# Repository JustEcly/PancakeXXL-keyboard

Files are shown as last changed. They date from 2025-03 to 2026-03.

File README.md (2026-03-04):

# PancakeXXL keyboard

  

This 40% is made in the idea of a little keyboard easy to travel with is little format and is 3d printed case to be lightweight.
This keyboard is made QMK and work with VIAL to make it customisable by everyone ! 

## Special thanks
I made it integrally but I take for inspiration for the layout the [Tanuki](https://github.com/SethSenpai/Tanuki) and get help from the [HLB team](https://github.com/H3lli0n/HLB-Projects) for some aspect of the keyboard (especially thanks to Please to help me with the PCB part and Hellion to help me with the case and firmware problems)

---
# Layout
Like say earlier I took inspiration of the Tanuki for the layout, but modify the last row by making it with a center Fn and not on the side, I also make it compatible with a 7u option.
To use the 7u layout you gonna need a special plate in the [plate and case directory](/plate_and_case/) who's using clip-in 7u stab (using 7u screw-in stab would have caused overlapping issues with switches) and activate the option on vial in the Layout tab
 ## Layout 2x2u and 7u
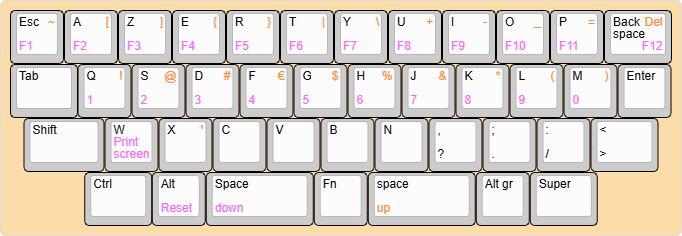
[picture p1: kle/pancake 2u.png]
Layout 2x2u

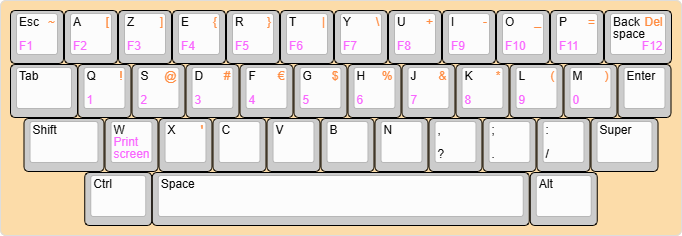
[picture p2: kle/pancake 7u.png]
Layout 7u


With the 2x2u you have an hold mod to use the up and down layer, you can customise it if you prefer to don't have it.

---
# QMK
The keyboard is made with a RP2040 MCU from rasbperry pi integrated on the PCB itself. This is a powerful MCU capable of a lot of thing like using QMK and by extension the VIAL application for easy modification of the keyboard.

---
# How to install the firmware
To install the firmware, you just need the uf2 files you can find in the [realease](https://github.com/JustEcly/PancakeXXL-keyboard/releases) or in the firmawre folder in the "[production_files](/production_files/firmware/)"
After downloading it, you need to connect the keyboard to your computer and slide the uf2 files in the directory that just open

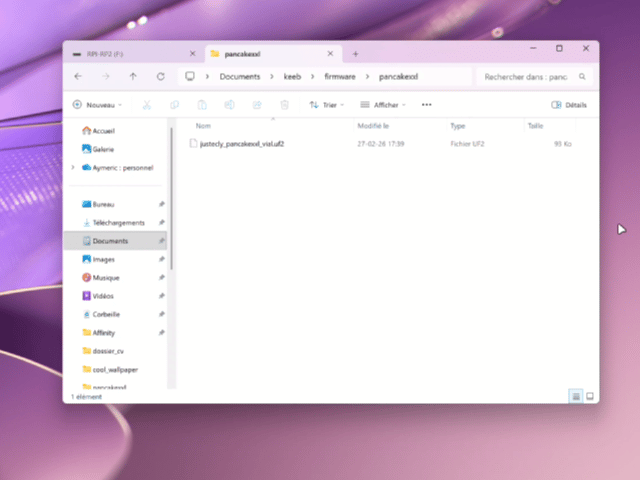
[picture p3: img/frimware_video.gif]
firmawre_video


Good job ! You now have a functionnal PCB & keyboard 👍

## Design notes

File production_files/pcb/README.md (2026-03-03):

# WARNING
some of the composant are'nt in the right position, to be sure to make a working pcb be sure to have the right orientation like the image below :
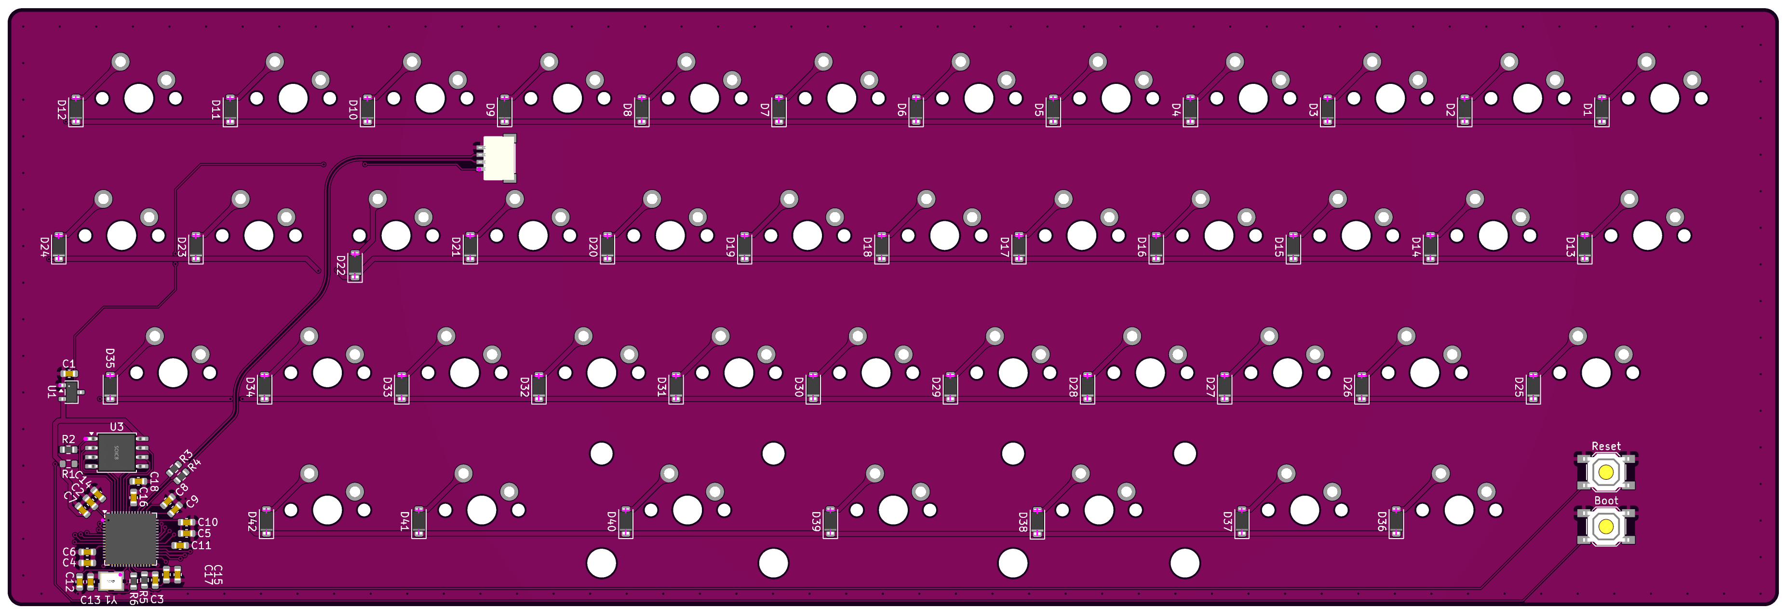
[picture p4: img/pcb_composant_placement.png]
image of the composant placement


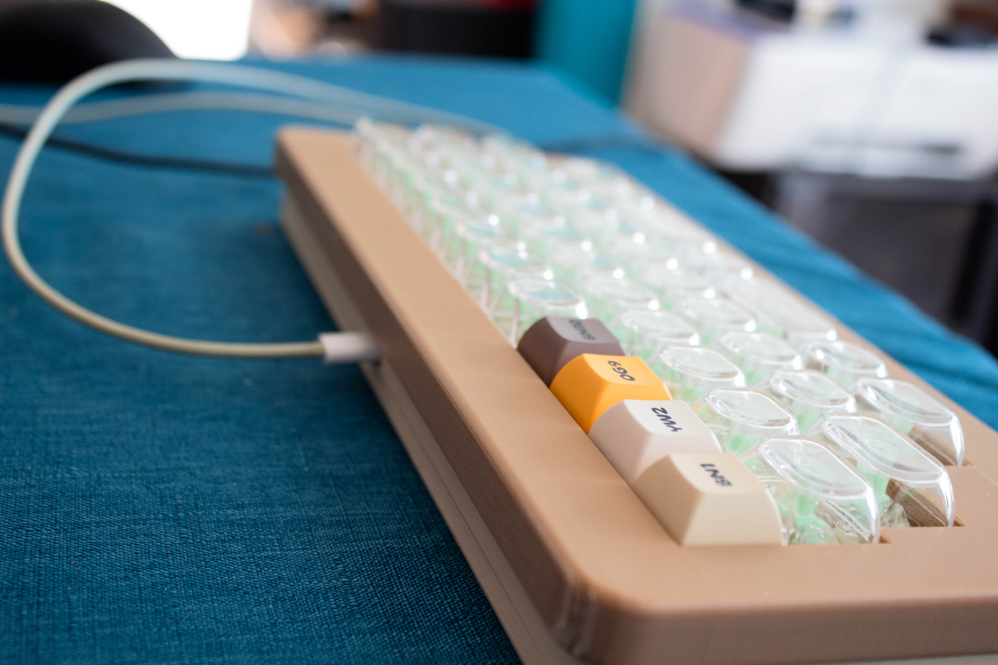
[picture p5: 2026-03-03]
img/pancakexxl_proto4-5.jpg

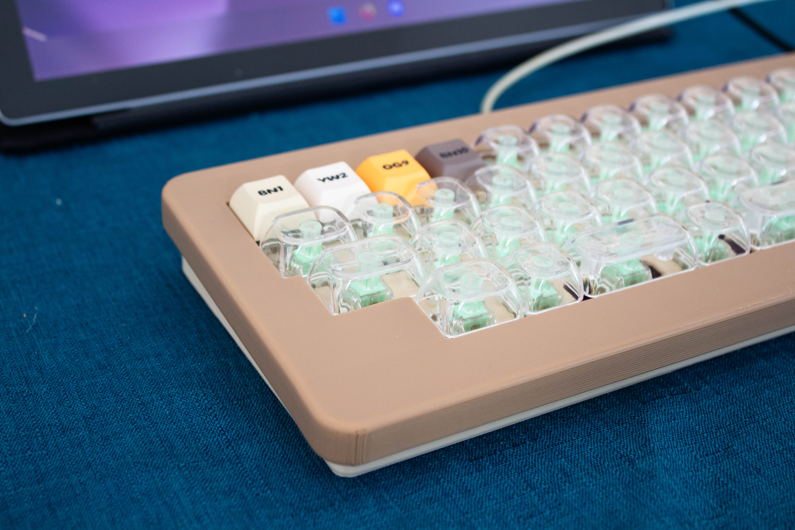
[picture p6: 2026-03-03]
img/pancakexxl_proto4-2.jpg

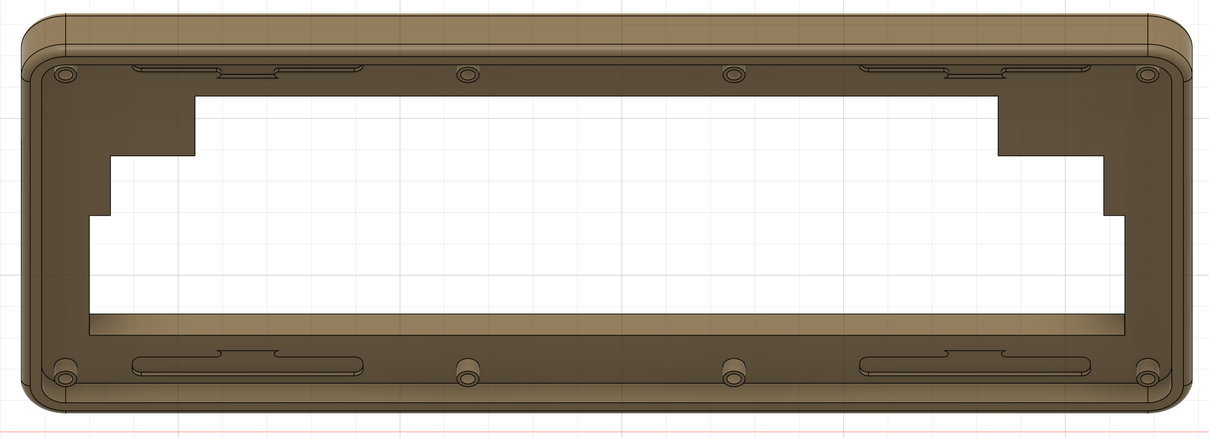
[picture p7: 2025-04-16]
plate_and_case/img/Back top-case.png

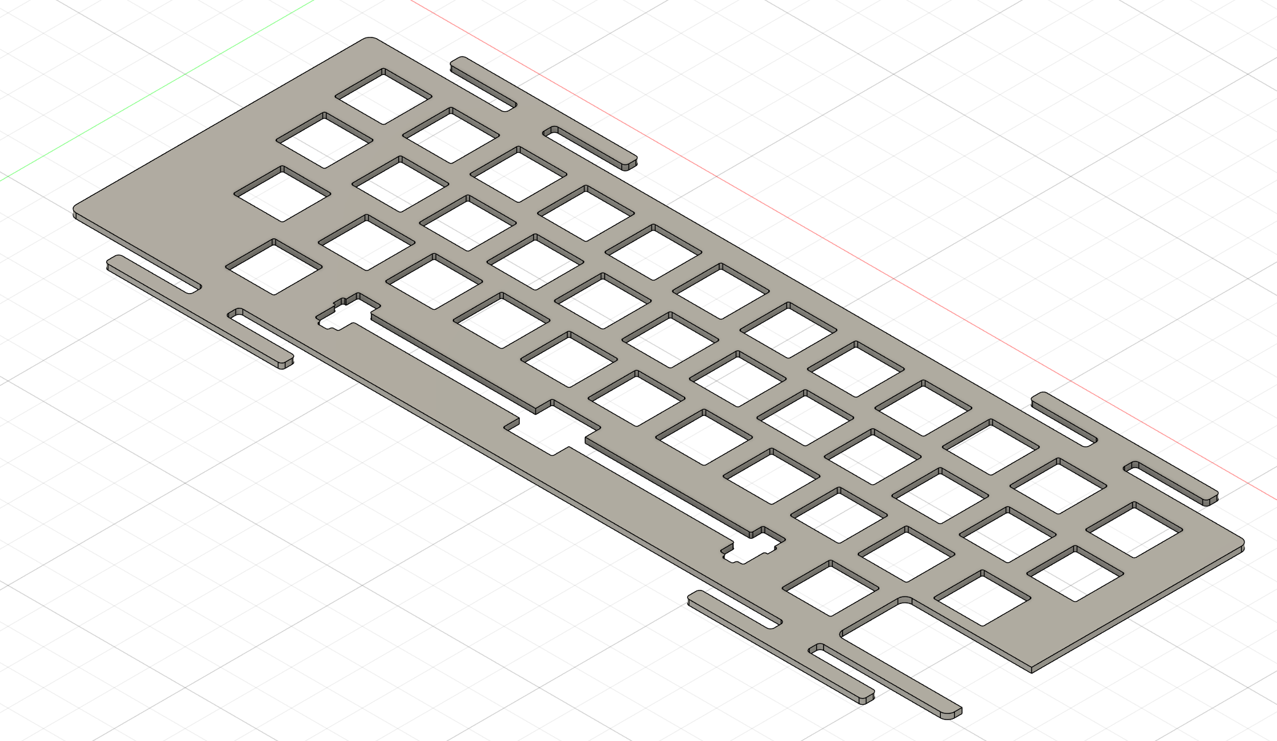
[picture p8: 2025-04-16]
plate_and_case/img/Plate 7u.png

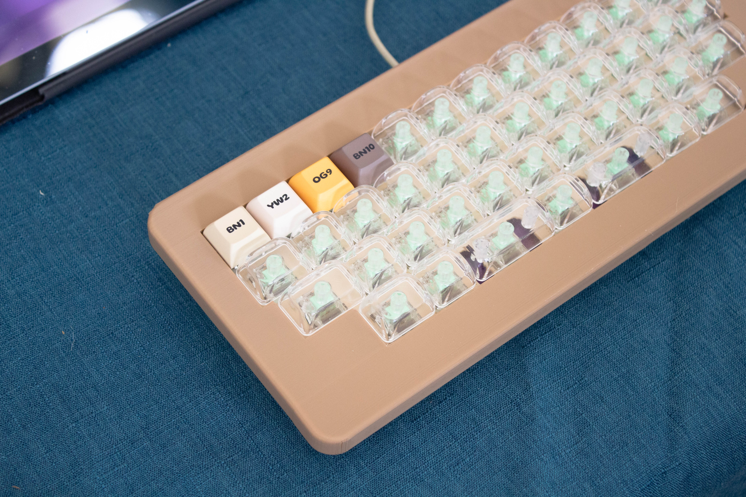
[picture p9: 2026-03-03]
img/pancakexxl_proto4-1.jpg

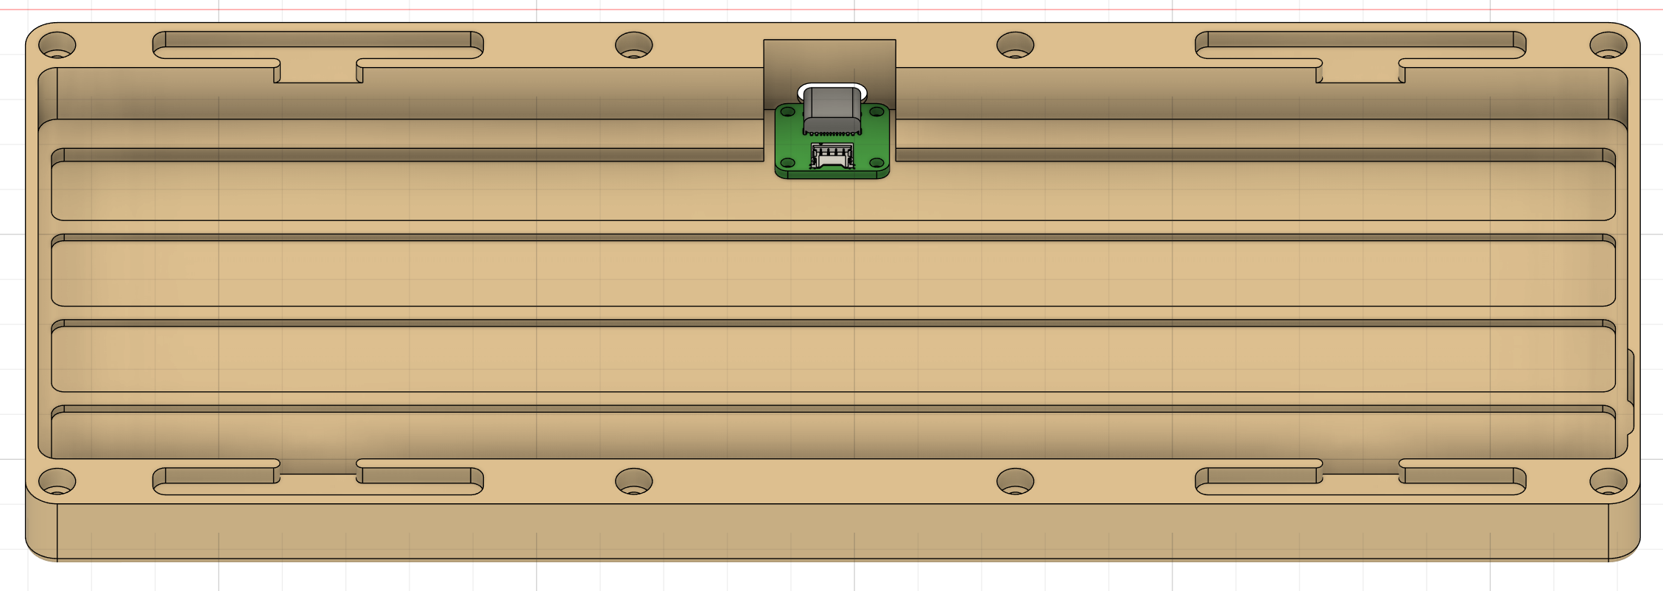
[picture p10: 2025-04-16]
plate_and_case/img/front bottom-case + UDB.png

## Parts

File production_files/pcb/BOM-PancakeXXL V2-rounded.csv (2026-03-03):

Comment | Designator | Footprint | LCSC | Quantity
100n | C11,C14,C15,C16,C17,C3,C4,C5,C6,C7,C8,C9 | C_0603_1608Metric | C1590 | 12
10u | C2 | C_0603_1608Metric | C1691 | 1
10uF | C1 | C_0603_1608Metric | C1691 | 1
15p | C12,C13 | C_0603_1608Metric | C1644 | 2
1K | R2 | R_0603_1608Metric | C103209 | 1
1k | R5,R6 | R_0603_1608Metric | C103209 | 2
1u | C10,C18 | C_0603_1608Metric | C1592 | 2
27.4 | R3,R4 | R_0603_1608Metric | C22926 | 2
ABM8-272-T3 | Y1 | ABM8-272-T3_ABR | C20625731 | 1
Boot | Boot | SW_SPST_SKQG_WithStem | C115351 | 1
Conn_01x04 | J1 | JST-SR-4 | C160404 | 1
D_Small | D1,D10,D11,D12,D13,D14,D15,D16,D17,D18,D19,D2,D20,D21,D22,D23,D24,D25,D26,D27,D28,D29,D3,D30,D31,D32,D33,D34,D35,D36,D37,D38,D39,D4,D40,D41,D42,D5,D6,D7,D8,D9 | D_SOD-123 | C7370889 | 42
RP2040 | U2 | QFN-56-1EP_7x7mm_P0.4mm_EP3.2x3.2mm | C2040 | 1
Reset | Reset | SW_SPST_SKQG_WithStem | C115351 | 1
W25Q128JVS | U3 | SOIC-8_5.23x5.23mm_P1.27mm | C97521 | 1
XC6206PxxxMR | U1 | SOT-23-3 | C5446 | 1
MX-NoLED | MX16 | MX_PCB_1.00u |  | 1
MX-NoLED | MX32 | MX_PCB_1.00u |  | 1
MX-NoLED | MX12 | MX_PCB_1.25u |  | 1
MX-NoLED | MX6 | MX_PCB_1.00u |  | 1
MX-NoLED | MX27 | MX_PCB_1.00u |  | 1
MX-NoLED | MX35 | MX_PCB_1.25u |  | 1
MX-NoLED | MX38 | MX_PCB_2.00u |  | 1
MX-NoLED | MX28 | MX_PCB_1.00u |  | 1
MX-NoLED | MX40 | MX_PCB_2.00u |  | 1
MX-NoLED | MX1 | MX_PCB_1.00u |  | 1
MX-NoLED | MX31 | MX_PCB_1.00u |  | 1
MX-NoLED | MX36 | MX_PCB_1.25u |  | 1
MX-NoLED | MX42 | MX_PCB_1.25u |  | 1
MX-NoLED | MX26 | MX_PCB_1.00u |  | 1
MX-NoLED | MX34 | MX_PCB_1.00u |  | 1
MX-NoLED | MX37 | MX_PCB_1.00u |  | 1
MX-NoLED | MX10 | MX_PCB_1.00u |  | 1
MX-NoLED | MX20 | MX_PCB_1.00u |  | 1
MX-NoLED | MX30 | MX_PCB_1.00u |  | 1
MX-NoLED | MX23 | MX_PCB_1.00u |  | 1
MX-NoLED | MX13 | MX_PCB_1.25u |  | 1
MX-NoLED | MX2 | MX_PCB_1.00u |  | 1
MX-NoLED | MX18 | MX_PCB_1.00u |  | 1
MX-NoLED | MX24 | MX_PCB_1.00u |  | 1
MX-NoLED | MX7 | MX_PCB_1.00u |  | 1
MX-NoLED | MX5 | MX_PCB_1.00u |  | 1
MX-NoLED | MX33 | MX_PCB_1.00u |  | 1
MX-NoLED | MX4 | MX_PCB_1.00u |  | 1
MX-NoLED | MX11 | MX_PCB_1.00u |  | 1
MX-NoLED | MX9 | MX_PCB_1.00u |  | 1
MX-NoLED | MX19 | MX_PCB_1.00u |  | 1
MX-NoLED | MX14 | MX_PCB_1.00u |  | 1
MX-NoLED | MX39 | MX_PCB_1.00u |  | 1
MX-NoLED | MX17 | MX_PCB_1.00u |  | 1
MX-NoLED | MX22 | MX_PCB_1.00u |  | 1
MX-NoLED | MX41 | MX_PCB_1.00u |  | 1
MX-NoLED | MX21 | MX_PCB_1.00u |  | 1
MX-NoLED | MX8 | MX_PCB_1.00u |  | 1
MX-NoLED | MX29 | MX_PCB_1.00u |  | 1
MX-NoLED | MX3 | MX_PCB_1.00u |  | 1
MX-NoLED | MX15 | MX_PCB_1.00u |  | 1
MX-NoLED | MX25 | MX_PCB_1.50u |  | 1
DNF | R1 | R_0603_1608Metric |  | 1

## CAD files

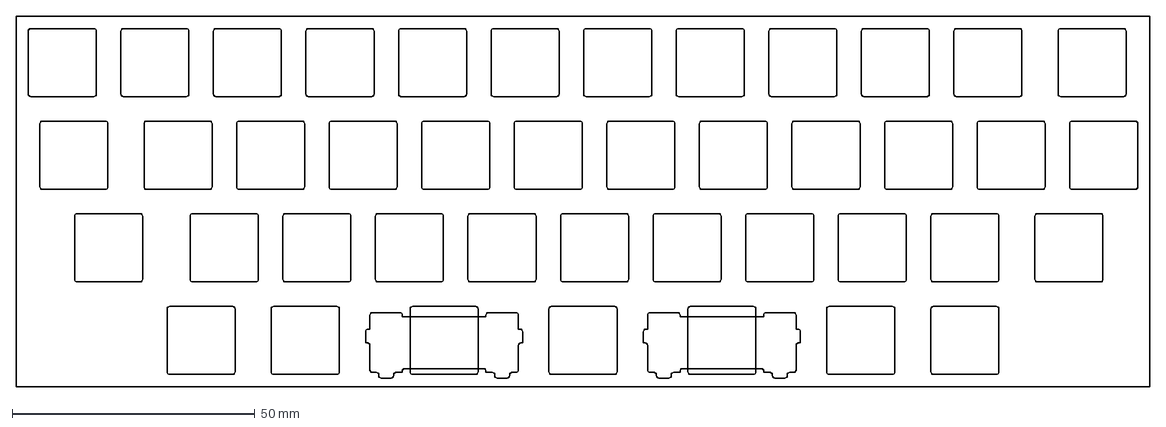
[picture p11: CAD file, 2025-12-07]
plate_and_case/dxf (PCB & Plate)/2U clip.dxf
233.4 x 76.2 mm

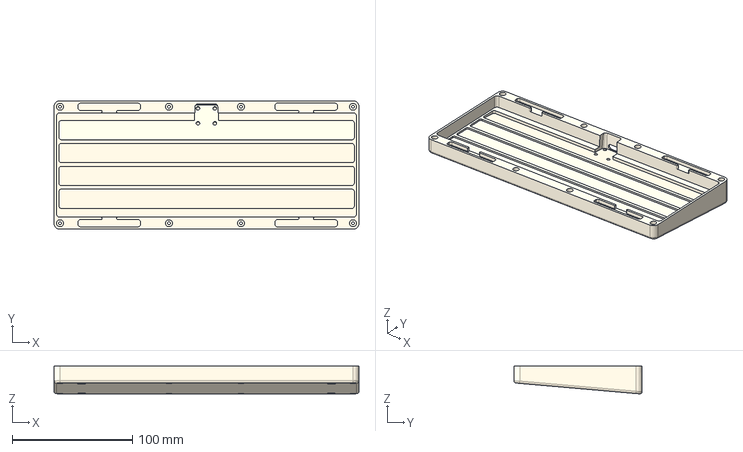
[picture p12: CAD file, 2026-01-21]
production_files/plate_and_case/step/Bottom case (v0.5).step
254.0 x 107.0 x 23.2 mm

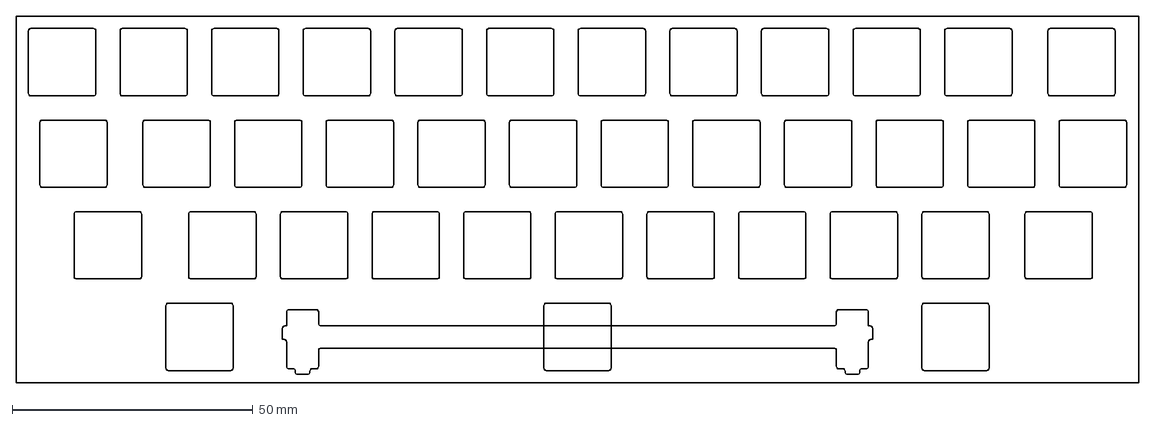
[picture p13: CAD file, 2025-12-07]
plate_and_case/dxf (PCB & Plate)/7u clip.dxf
233.4 x 76.2 mm

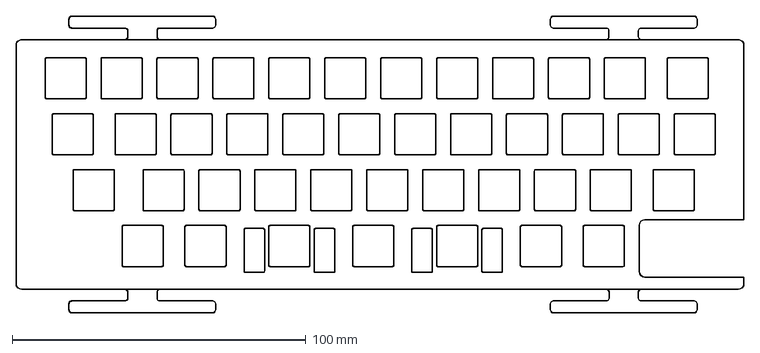
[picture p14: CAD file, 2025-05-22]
plate_and_case/Foam/Foam 2u.dxf
248.0 x 101.0 mm

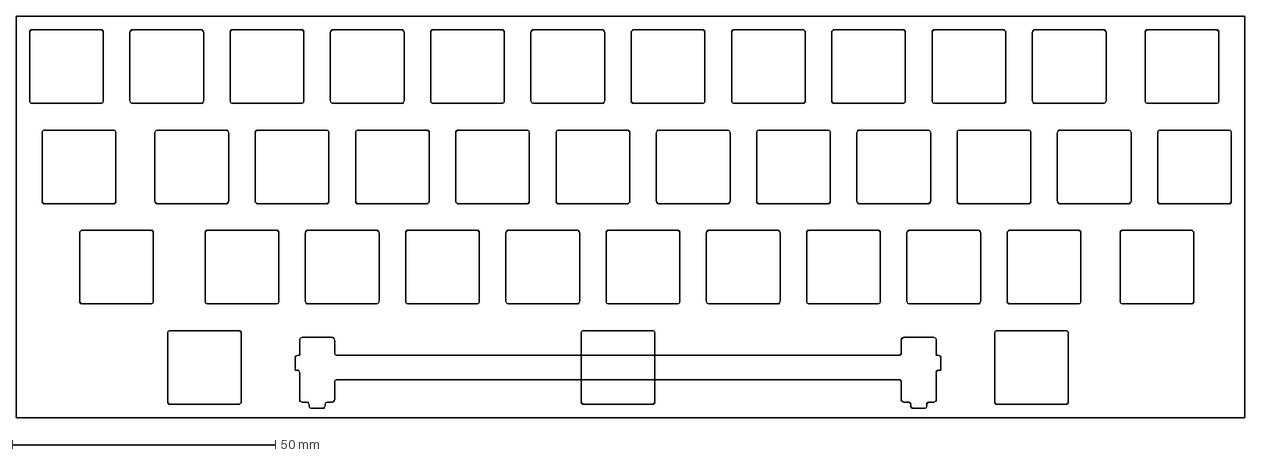
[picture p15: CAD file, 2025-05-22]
plate_and_case/Plate Ai03 - dxf & svg/7u clip.dxf
233.4 x 76.2 mm

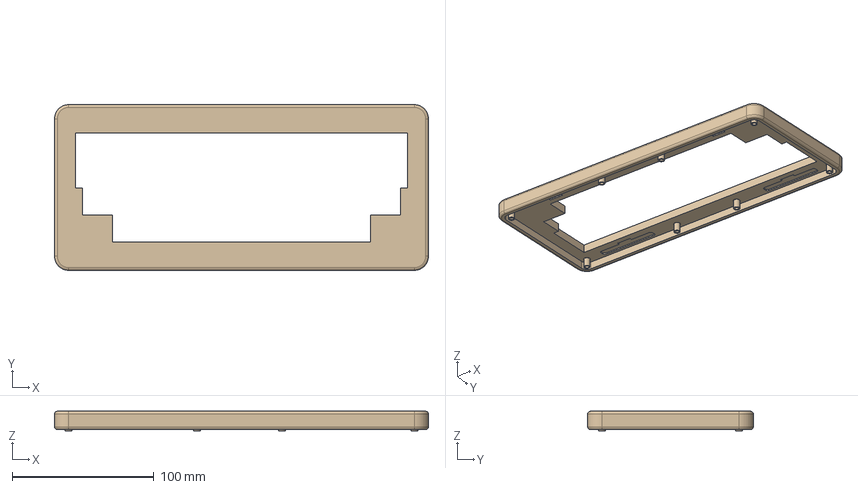
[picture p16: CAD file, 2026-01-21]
production_files/plate_and_case/step/Top case (v0.5).step
264.0 x 117.0 x 13.8 mm

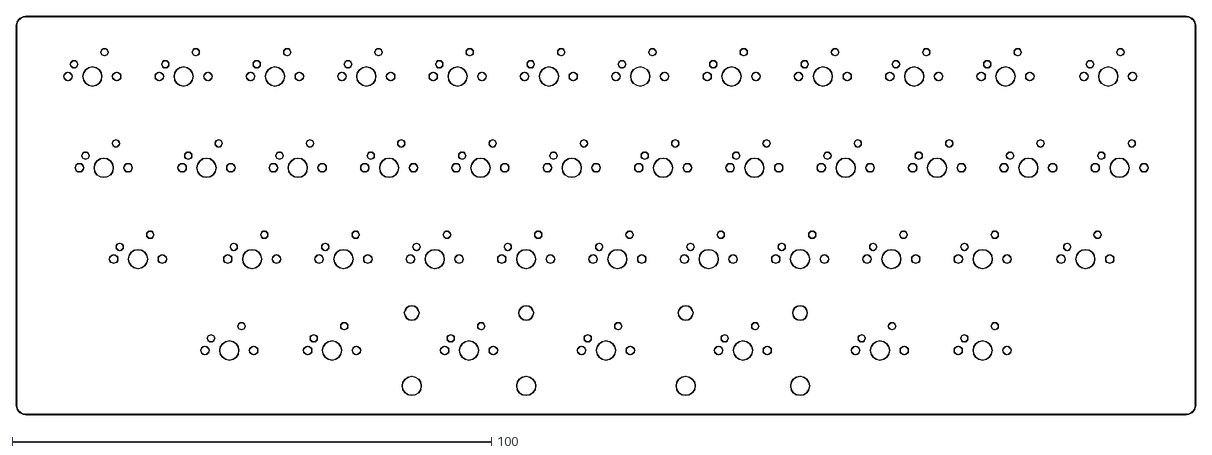
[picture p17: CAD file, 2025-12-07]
plate_and_case/dxf (PCB & Plate)/PancakeXXL V2-rounded-Edge_Cuts.dxf
246.1 x 83.0

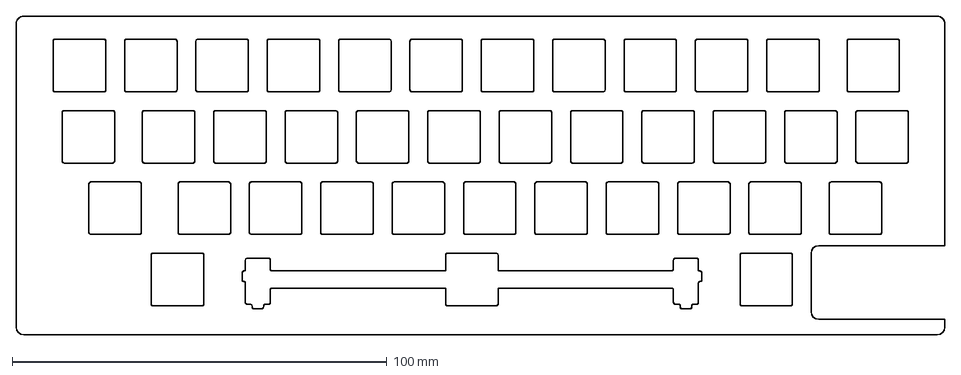
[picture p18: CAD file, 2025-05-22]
plate_and_case/Foam/Plate 7u clip.dxf
248.0 x 85.0 mm

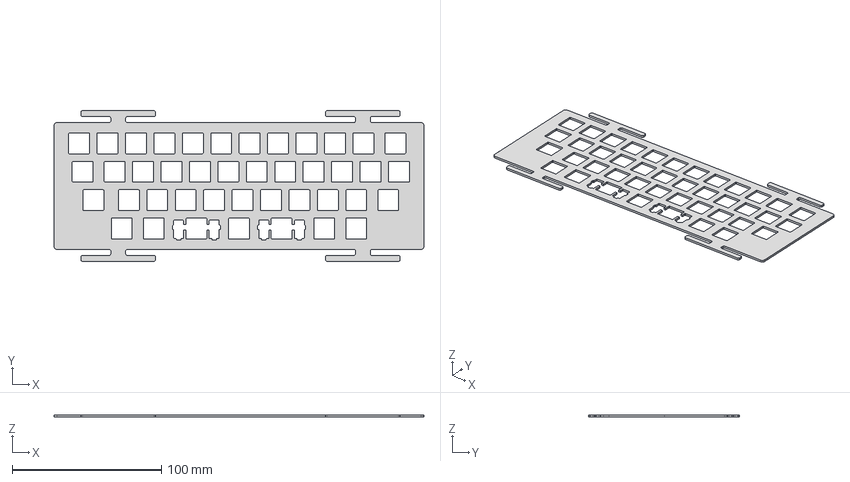
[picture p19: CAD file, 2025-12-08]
production_files/plate_and_case/step/Plate 2u Clip (v0.4).step
248.0 x 101.0 x 1.50 mm

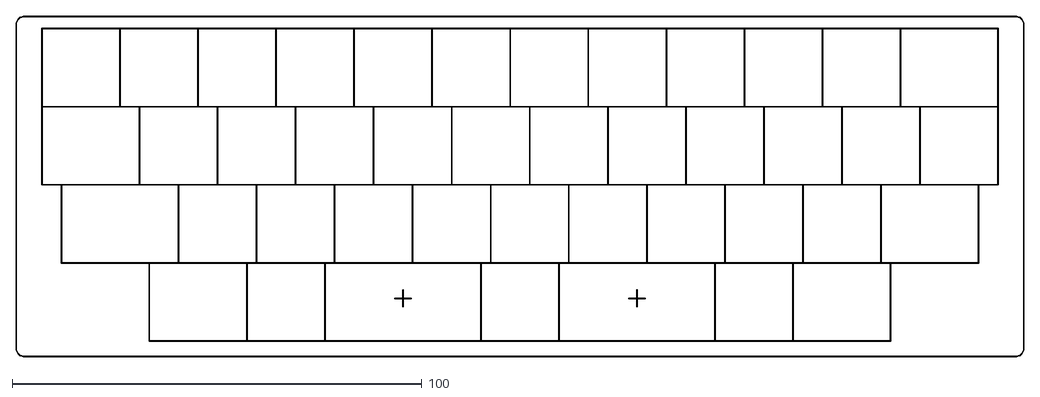
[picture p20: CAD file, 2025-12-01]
plate_and_case/dxf (PCB & Plate)/Trou top case.dxf
246.1 x 83.0

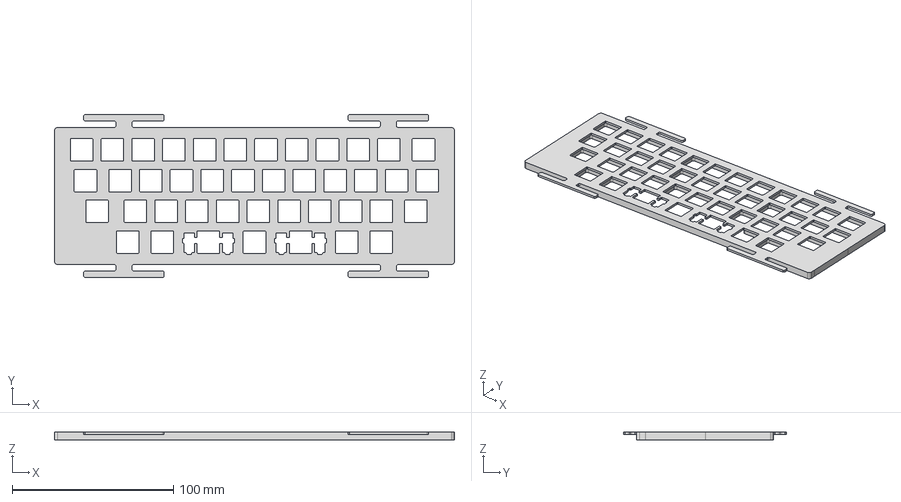
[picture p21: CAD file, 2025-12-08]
production_files/plate_and_case/step/Plate 2u Clip (3dp renfort) (v0.4).step
248.0 x 101.0 x 4.90 mm

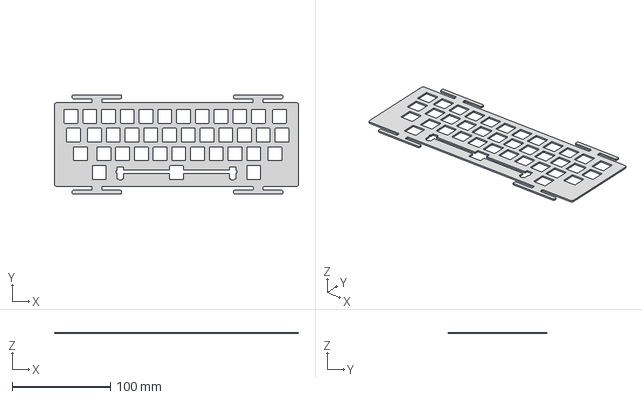
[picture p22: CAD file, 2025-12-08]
production_files/plate_and_case/step/Plate 7u clip (v0.4).step
248.0 x 101.0 x 1.50 mm

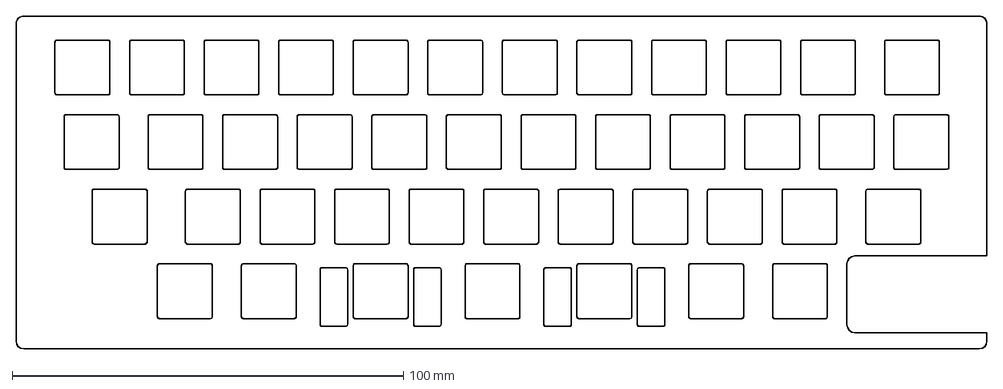
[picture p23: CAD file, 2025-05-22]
plate_and_case/Foam/Plate 2u Screw.dxf
248.0 x 85.0 mm

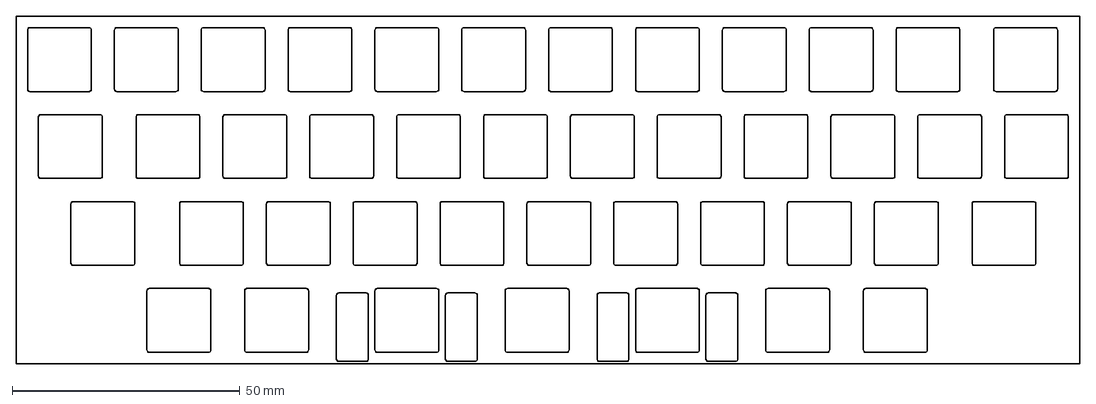
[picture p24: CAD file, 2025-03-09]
plate_and_case/Plate Ai03 - dxf & svg/2u screw.dxf
233.4 x 76.2 mm

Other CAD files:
production_files/plate_and_case/step/Plate 2u screw (v0.4).step
production_files/plate_and_case/stl/Bottom case (v0.5).stl
production_files/plate_and_case/stl/Plate 2u Clip (3dp renfort) (v0.4).stl
production_files/plate_and_case/stl/Plate 2u Clip (v0.4).stl
production_files/plate_and_case/stl/Plate 2u screw (v0.4).stl
production_files/plate_and_case/stl/Plate 7u clip (v0.4).stl
production_files/plate_and_case/stl/Top case (v0.5).stl

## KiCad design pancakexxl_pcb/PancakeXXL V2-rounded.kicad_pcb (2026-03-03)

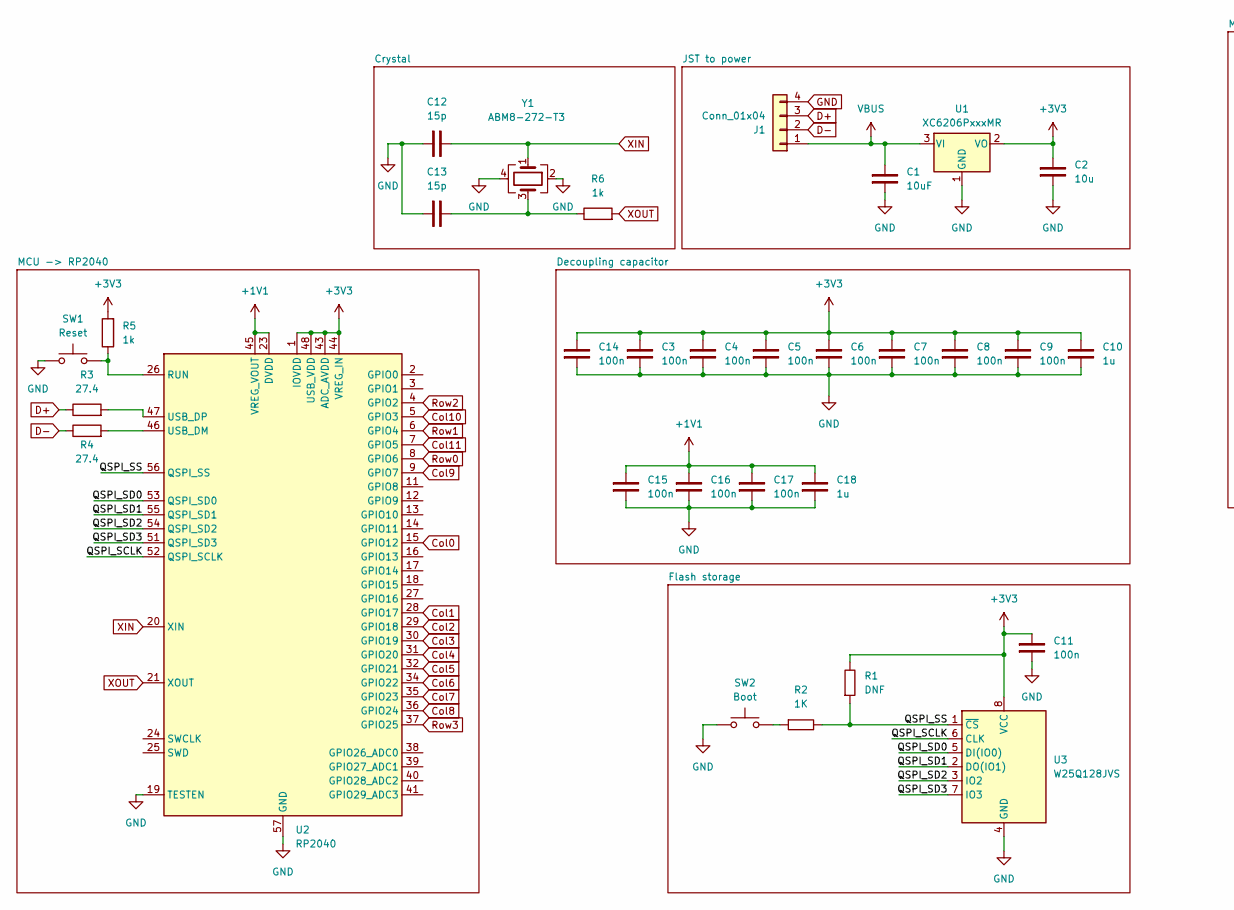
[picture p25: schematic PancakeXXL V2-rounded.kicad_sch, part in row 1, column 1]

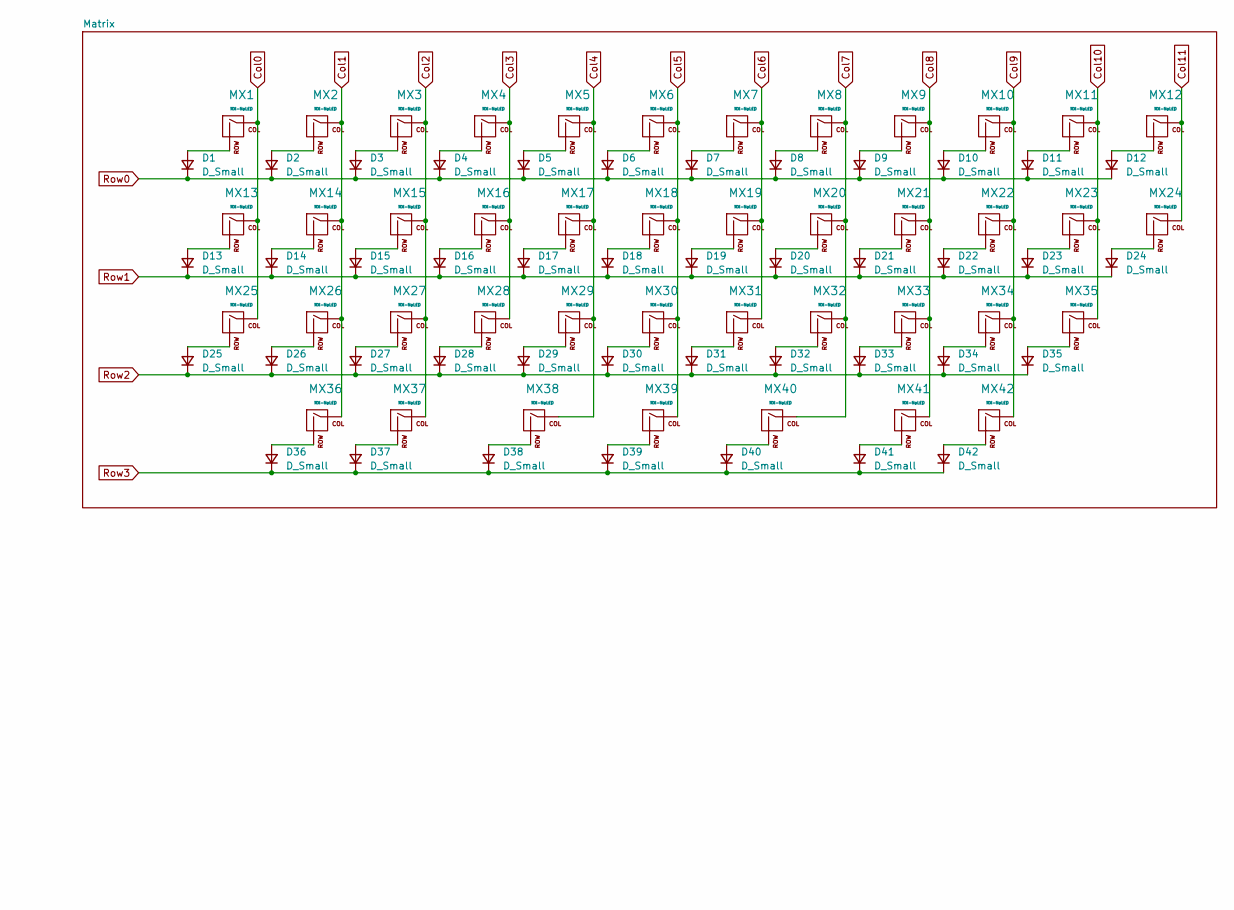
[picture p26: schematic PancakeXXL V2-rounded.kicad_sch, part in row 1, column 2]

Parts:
C1: 10uF; C_0603_1608Metric
C2: 10u; C_0603_1608Metric
C3, C4, C5, C6, C7, C8, C9, C11, C14, C15, C16, C17: 100n; C_0603_1608Metric
C10, C18: 1u; C_0603_1608Metric
C12, C13: 15p; C_0603_1608Metric
D1, D2, D3, D4, D5, D6, D7, D8, D9, D10, D11, D12, D13, D14, D15, D16, D17, D18, D19, D20, D21, D22, D23, D24, D25, D26, D27, D28, D29, D30, D31, D32, D33, D34, D35, D36, D37, D38, D39, D40, D41, D42: D_Small; D_SOD-123
J1: Conn_01x04; JST-SR-4; Part Number 1-0401FBV0T
MX1, MX2, MX3, MX4, MX5, MX6, MX7, MX8, MX9, MX10, MX11, MX14, MX15, MX16, MX17, MX18, MX19, MX20, MX21, MX22, MX23, MX24, MX26, MX27, MX28, MX29, MX30, MX31, MX32, MX33, MX34, MX37, MX39, MX41: MX-NoLED; MX_PCB_1.00u
MX12, MX13, MX35, MX36, MX42: MX-NoLED; MX_PCB_1.25u
MX25: MX-NoLED; MX_PCB_1.50u
MX38, MX40: MX-NoLED; MX_PCB_2.00u
R1: DNF; R_0603_1608Metric
R2: 1K; R_0603_1608Metric
R3, R4: 27.4; R_0603_1608Metric
R5, R6: 1k; R_0603_1608Metric
SW1: Reset; SW_SPST_SKQG_WithStem
SW2: Boot; SW_SPST_SKQG_WithStem
U1: XC6206PxxxMR; SOT-23-3
U2: RP2040; QFN-56-1EP_7x7mm_P0.4mm_EP3.2x3.2mm
U3: W25Q128JVS; SOIC-8_5.23x5.23mm_P1.27mm
Y1: ABM8-272-T3; ABM8-272-T3_ABR

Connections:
+1V1: C15.2, C16.2, C17.2, C18.2, U2.23 (DVDD), U2.45 (VREG_VOUT), U2.50 (DVDD)
+3V3: C2.2, C3.2, C4.2, C5.2, C6.2, C7.2, C8.2, C9.2, C10.2, C11.2, C14.2, R1.2, R5.2, U1.2 (VO), U2.1 (IOVDD), U2.10 (IOVDD), U2.22 (IOVDD), U2.33 (IOVDD), U2.42 (IOVDD), U2.43 (ADC_AVDD), U2.44 (VREG_IN), U2.48 (USB_VDD), U2.49 (IOVDD), U3.8 (VCC)
/QSPI_SCLK: U2.52 (QSPI_SCLK), U3.6 (CLK)
/QSPI_SD0: U2.53 (QSPI_SD0), U3.5 (DI(IO0))
/QSPI_SD1: U2.55 (QSPI_SD1), U3.2 (DO(IO1))
/QSPI_SD2: U2.54 (QSPI_SD2), U3.3 (IO2)
/QSPI_SD3: U2.51 (QSPI_SD3), U3.7 (IO3)
/QSPI_SS: R1.1, R2.2, U2.56 (QSPI_SS), U3.1 (~CS)
Col0: MX1.1 (COL), MX13.1 (COL), MX25.1 (COL), U2.15 (GPIO12)
Col1: MX2.1 (COL), MX14.1 (COL), MX26.1 (COL), MX36.1 (COL), U2.28 (GPIO17)
Col2: MX3.1 (COL), MX15.1 (COL), MX27.1 (COL), MX37.1 (COL), U2.29 (GPIO18)
Col3: MX4.1 (COL), MX16.1 (COL), MX28.1 (COL), U2.30 (GPIO19)
Col4: MX5.1 (COL), MX17.1 (COL), MX29.1 (COL), MX38.1 (COL), U2.31 (GPIO20)
Col5: MX6.1 (COL), MX18.1 (COL), MX30.1 (COL), MX39.1 (COL), U2.32 (GPIO21)
Col6: MX7.1 (COL), MX19.1 (COL), MX31.1 (COL), U2.34 (GPIO22)
Col7: MX8.1 (COL), MX20.1 (COL), MX32.1 (COL), MX40.1 (COL), U2.35 (GPIO23)
Col8: MX9.1 (COL), MX21.1 (COL), MX33.1 (COL), MX41.1 (COL), U2.36 (GPIO24)
Col9: MX10.1 (COL), MX22.1 (COL), MX34.1 (COL), MX42.1 (COL), U2.9 (GPIO7)
Col10: MX11.1 (COL), MX23.1 (COL), MX35.1 (COL), U2.5 (GPIO3)
Col11: MX12.1 (COL), MX24.1 (COL), U2.7 (GPIO5)
D+: J1.3, R3.1
D-: J1.2, R4.1
GND: C1.1, C2.1, C3.1, C4.1, C5.1, C6.1, C7.1, C8.1, C9.1, C10.1, C11.1, C12.1, C13.1, C14.1, C15.1, C16.1, C17.1, C18.1, J1.4, SW1.1, SW2.1, U1.1 (GND), U2.19 (TESTEN), U2.57 (GND), U3.4 (GND), Y1.2, Y1.4; also elsewhere on the board
unnamed: C13.2, R6.1, Y1.3
unnamed: D1.2 (A), MX1.2 (ROW)
unnamed: D2.2 (A), MX2.2 (ROW)
unnamed: D3.2 (A), MX3.2 (ROW)
unnamed: D4.2 (A), MX4.2 (ROW)
unnamed: D5.2 (A), MX5.2 (ROW)
unnamed: D6.2 (A), MX6.2 (ROW)
unnamed: D7.2 (A), MX7.2 (ROW)
unnamed: D8.2 (A), MX8.2 (ROW)
unnamed: D9.2 (A), MX9.2 (ROW)
unnamed: D10.2 (A), MX10.2 (ROW)
unnamed: D11.2 (A), MX11.2 (ROW)
unnamed: D12.2 (A), MX12.2 (ROW)
unnamed: D13.2 (A), MX13.2 (ROW)
unnamed: D14.2 (A), MX14.2 (ROW)
unnamed: D15.2 (A), MX15.2 (ROW)
unnamed: D16.2 (A), MX16.2 (ROW)
unnamed: D17.2 (A), MX17.2 (ROW)
unnamed: D18.2 (A), MX18.2 (ROW)
unnamed: D19.2 (A), MX19.2 (ROW)
unnamed: D20.2 (A), MX20.2 (ROW)
unnamed: D21.2 (A), MX21.2 (ROW)
unnamed: D22.2 (A), MX22.2 (ROW)
unnamed: D23.2 (A), MX23.2 (ROW)
unnamed: D24.2 (A), MX24.2 (ROW)
unnamed: D25.2 (A), MX25.2 (ROW)
unnamed: D26.2 (A), MX26.2 (ROW)
unnamed: D27.2 (A), MX27.2 (ROW)
unnamed: D28.2 (A), MX28.2 (ROW)
unnamed: D29.2 (A), MX29.2 (ROW)
unnamed: D30.2 (A), MX30.2 (ROW)
unnamed: D31.2 (A), MX31.2 (ROW)
unnamed: D32.2 (A), MX32.2 (ROW)
unnamed: D33.2 (A), MX33.2 (ROW)
unnamed: D34.2 (A), MX34.2 (ROW)
unnamed: D35.2 (A), MX35.2 (ROW)
unnamed: D36.2 (A), MX36.2 (ROW)
unnamed: D37.2 (A), MX37.2 (ROW)
unnamed: D38.2 (A), MX38.2 (ROW)
unnamed: D39.2 (A), MX39.2 (ROW)
unnamed: D40.2 (A), MX40.2 (ROW)
unnamed: D41.2 (A), MX41.2 (ROW)
unnamed: D42.2 (A), MX42.2 (ROW)
unnamed 66: R2.1, SW2.2; also elsewhere on the board
unnamed 67: R5.1, SW1.2, U2.26 (RUN); also elsewhere on the board
unnamed: R4.2, U2.46 (USB_DM)
unnamed: R3.2, U2.47 (USB_DP)
Row0: D1.1 (K), D2.1 (K), D3.1 (K), D4.1 (K), D5.1 (K), D6.1 (K), D7.1 (K), D8.1 (K), D9.1 (K), D10.1 (K), D11.1 (K), D12.1 (K), U2.8 (GPIO6)
Row1: D13.1 (K), D14.1 (K), D15.1 (K), D16.1 (K), D17.1 (K), D18.1 (K), D19.1 (K), D20.1 (K), D21.1 (K), D22.1 (K), D23.1 (K), D24.1 (K), U2.6 (GPIO4)
Row2: D25.1 (K), D26.1 (K), D27.1 (K), D28.1 (K), D29.1 (K), D30.1 (K), D31.1 (K), D32.1 (K), D33.1 (K), D34.1 (K), D35.1 (K), U2.4 (GPIO2)
Row3: D36.1 (K), D37.1 (K), D38.1 (K), D39.1 (K), D40.1 (K), D41.1 (K), D42.1 (K), U2.37 (GPIO25)
VBUS: C1.2, J1.1, U1.3 (VI)
XIN: C12.2, U2.20 (XIN), Y1.1
XOUT: R6.2, U2.21 (XOUT)

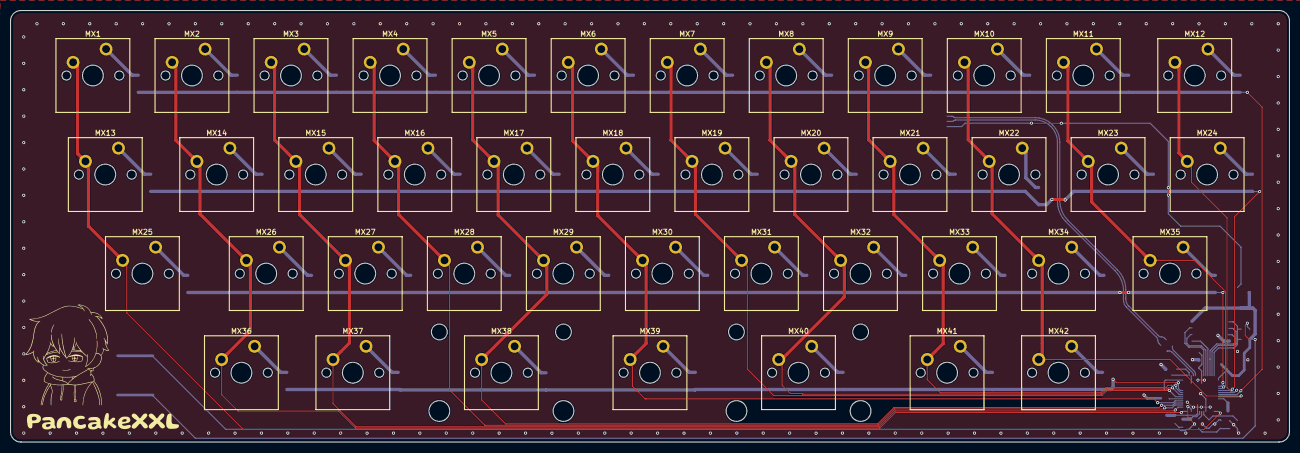
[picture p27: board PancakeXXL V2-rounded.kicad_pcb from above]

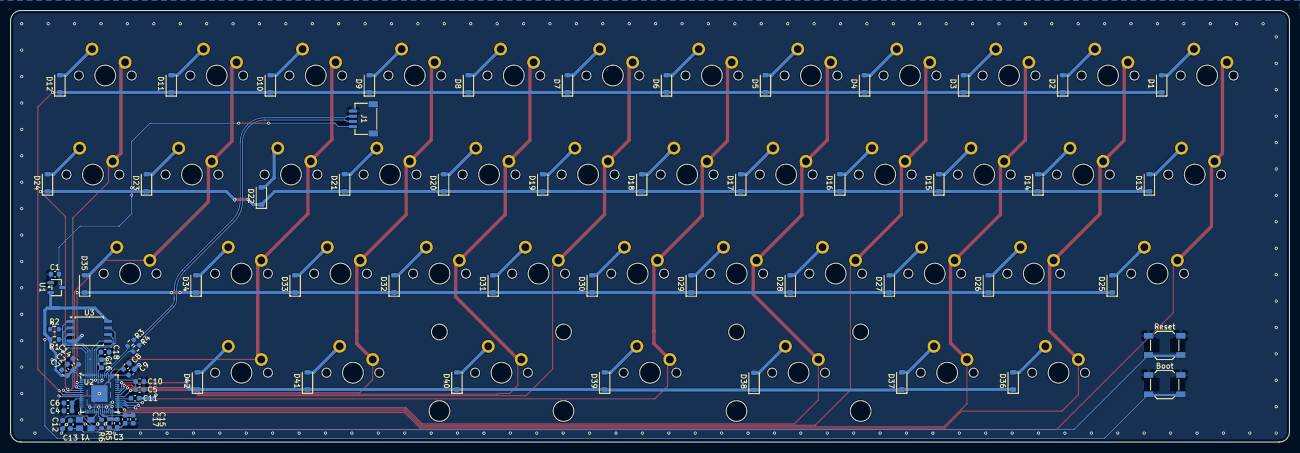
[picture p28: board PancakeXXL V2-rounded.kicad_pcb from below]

Board: 2 copper layers, 246.0 x 83.0 mm, 115 parts (73 on the bottom side), 77 nets.

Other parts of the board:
Boot: Boot; SW_SPST_SKQG_WithStem
Reset: Reset; SW_SPST_SKQG_WithStem

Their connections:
GND: Boot.1, Reset.1; also elsewhere on the board
unnamed 66: Boot.2; also elsewhere on the board
unnamed 67: Reset.2; also elsewhere on the board

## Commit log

2025-01-31 Kicad files
    Statring to create the kicad files
    [Pancake.kicad_pcb, Pancake.kicad_sch]
2025-02-02 Strart the schematics
    [Pancake.kicad_sch]
2025-02-10 KLE and Datasheet
    Add to the folder the datasheet of the RP2040 Pro Micro controller and the Keyboard Layout Editor files
    [Pancake.kicad_sch]
2025-02-11 Lib modification
    I change my library for my micro controller to use the RP2040 Pro Micro from 42Keebs
    [Pancake.kicad_sch]
2025-02-13 A lot of modification
    addition of a jst cable and other
    [Pancake.kicad_pcb, Pancake.kicad_sch]
2025-02-24 Many change
    [Pancake.kicad_pcb]
2025-03-09 Modification complète du PCB et fichier de production
    Flemme de faire en anglais au pire google traduction ça existe 😭
    J'ai complètement refait le pcb pour mettre les diodes derrière et donc refait tout le routing, en plus de ça j'ai fait les fichier pour faire produire le pcb par jlcpcb donc vous pourrez aussi le pr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
    [BOM-Pancake.csv, Pancake-JLCPCB.xlsx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]
2025-03-15 Creation of the case and the plate
    STEP and STL
    [Bottom case.step, Bottom case.stl, Pancake-F_Mask.dxf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]
2025-03-17 Mise à jour des STL et STEP
    J'ai du retravailler la case alors voici les nouvelles modification de bottom case, top case et plate
    [Bottom case.step, Bottom case.stl, Plate.step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]
2025-03-25 Pleins de modif sur la case
    Pleins de petite modification pour améliorer la case en général
    [Bottom case.step, Bottom case.stl, Plate.step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]
2025-03-25 Plate 7u Clip-in
    Ajout d'une plate 7u en cilp-in pour les fans de 7u
    [Plate 2u Screw.step, Plate 7u Clip.step, Plate.step]
2025-04-16 Image ajouter
    J'ai rajouter les images du clavier fait dans fusion 360
2025-04-23 Top V2
    Mise à jour de la case pour évitez les problèmes avec le micro controller
    [Top case.step]
2025-05-22 PCB last modification
    [2U.dxf, 7u.dxf, Foam 2u.dxf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]
2025-06-09 Update to pcb v2
    [BOM-Pancake.csv, BOM-PancakeXXL V2-rounded.csv, Bottom case.step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]
2025-08-08 Update QMK
    I update the qmk for the new pcb
    [MCU.kicad_sch, PancakeXXL V2-rounded.kicad_pcb, PancakeXXL V2.kicad_sch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]
2025-10-23 Mise à jour README
    [BOM-Pancake.csv, BOM-PancakeXXL V2-rounded.csv, MCU.kicad_sch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]
2025-12-01 C'était pas droit avant, mainteant le pcb et le KLE l'ai faut que je fasse la plate et la case mtn
    [Bottom case (v2).step, Bottom case (v2).stl, Bottom case.step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]
2025-12-07 Rectification KLE, 3D
    J'ai refait tout le design pour que cette fois-ci tout soit bien droit
    [2U clip.dxf, 7u clip.dxf, BOM-PancakeXXL V2-rounded.csv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]
2025-12-08 Modification plate clip-in
    Je l'ai es modifier sous conseil de Bagri pour les rendre plus solide
    [2u clip.dxf, 2u screw.dxf, 7u clip.dxf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]
2025-12-15 Léger ajustement
    [Top case.step, Top case.stl]
2026-03-03 update after many month
    Final design of the case,
    Final plate design,
    Final PCB for production,
    And many more
    [2U clip.dxf, 2u clip.dxf, 2u screw.dxf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]
2026-03-03 Production files update
    everytings needed to make the keyboard can be find in the general production files
    [Bottom case (v0.5).step, Bottom case (v0.5).stl, Plate 2u Clip (3dp renfort) (v0.4).step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]
2026-03-04 Update README.md
    start to casse me les couilles hein
